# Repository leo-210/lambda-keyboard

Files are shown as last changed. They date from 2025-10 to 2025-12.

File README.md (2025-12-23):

# Lambda keyboard

A custom 36-key wired ChocV1 split keyboard.

> Note : this keyboard is my first design, and while taking it as an inspiration
> can be a good idea, please think before building exactly this design : there
> are a few flaws that I wrote about below.

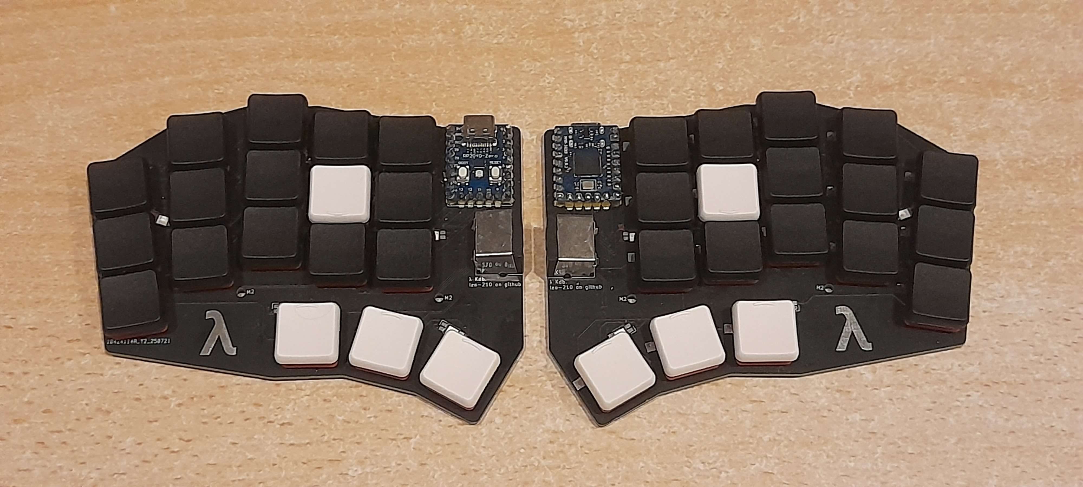
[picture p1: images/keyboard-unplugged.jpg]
Unplugged keyboard


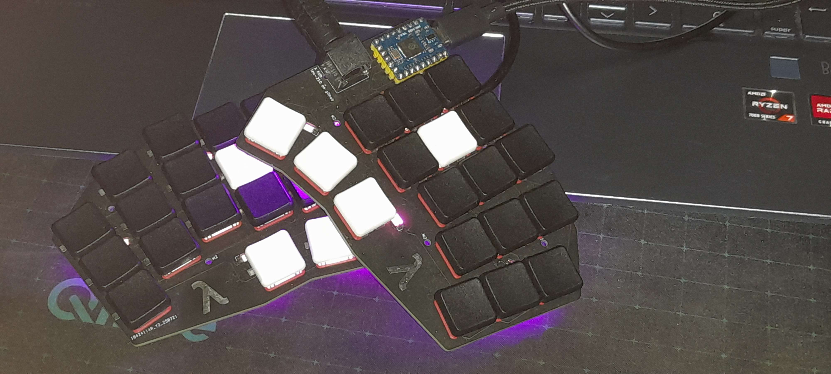
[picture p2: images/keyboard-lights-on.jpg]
Keyboard with lights on


# Building the keyboard

## Components

To build the keyboard, you'll need :
- 2 RP2040-Zero micro controllers
- 2 4-pin mini DIN connectors
- 5 YS-SK6812mini-e LEDs *(optional, the keyboard will work without them)*
- 36 Kailh hot-swappable sockets
- 36 **Choc v1** (and not Choc v2 !!) switches
- 36 **Choc v1** keycaps

The keyboard is diode-less !

You can also design your own case, but I did not bother.

## Price

Ordering everything in France, including soldering tools, it cost about 110 €,
where approximately a third was for electrical components and the PCB, a second
third for key caps and switches, and the last third for shipping costs.

## Firmware

This repo also contains QMK firmware for this keyboard, using the BÉPO french
layout. The keyboard layout was inspired by
[Miryoku](https://github.com/manna-harbour/miryoku), and you can view it on
[keyboard-layout-editor.com](https://www.keyboard-layout-editor.com/#/gists/44301debdf501308d3bc676f406fde57).

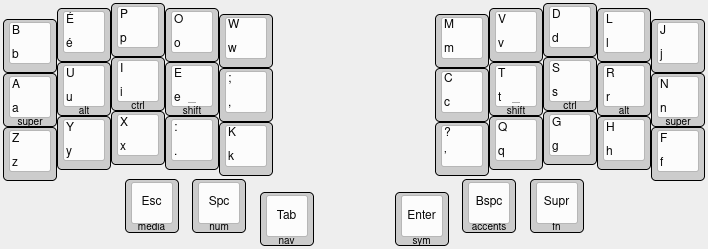
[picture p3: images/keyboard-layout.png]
Keyboard example layout


# About the project

## Why design yet another split keyboard ?

I fell into the rabbit hole of custom split keyboards, and with all the summer
holidays in front of me, I couldn't hold back. It was a fun project !

I chose to make my own design because none where satisfying all my requirements,
which were :
- Exactly 36 keys, I was afraid to go with only two thumb keys, but still wanted
  to go with few keys.
- A layout with enough stagger for my pinky.

With enough research I maybe could have found something, but designing it myself
was far more interesting. 

If you want a split keyboard, you can definitely think
about creating your own ! It is not as difficult as it would seem, and this
journey is well documented and there are a lot of tools to make your life
easier.

## Why lambda ?

I like this Greek letter, and my name starts with an L.

## Inspirations 

- the [Corne keyboard](https://github.com/foostan/crkbd) and the 
  [TOTEM keyboard](https://github.com/GEIGEIGEIST/TOTEM) for the layout (among 
  others)
- [axhixh/mini-kbd](https://github.com/axhixh/mini-kbd/tree/main) which helped
  me a lot to figure out the PCB design.

## What would I change ?

As my first design, nothing is perfect, and here are some things I would change
for a future design.

### A different connector

I like that the mini DIN protects my keyboard from shorting, but the cable is
really bulky. I'll think about changing to USB C next time, or just TRRS, even
with the lack of shorting safety.

### 4 rows instead of 3 to make writing french accents easier.

Writing in English is not a problem, but in french with accents everywhere I
find it painful to constantly use layers. It is possible and can even become
reliable, but for now I couldn't really get used to it (maybe I haven't used the
keyboard enough yet...).

Also, for coding, where a lot of special symbols are needed, a couple more keys
could be useful.

### More leds

Only 5 underglow LEDs are not enough in my opinion, you can see their light but
there are some "holes". Also, for a future keyboard I'd like per key lighting as
well, even if it requires more work.

### An OLED display

Seems fun.

### Writing JLCJLCJLC on the PCB

Without this text, JLC PCB wrote a random number in a random place on my PCBs...
Fortunately it does not look that bad.

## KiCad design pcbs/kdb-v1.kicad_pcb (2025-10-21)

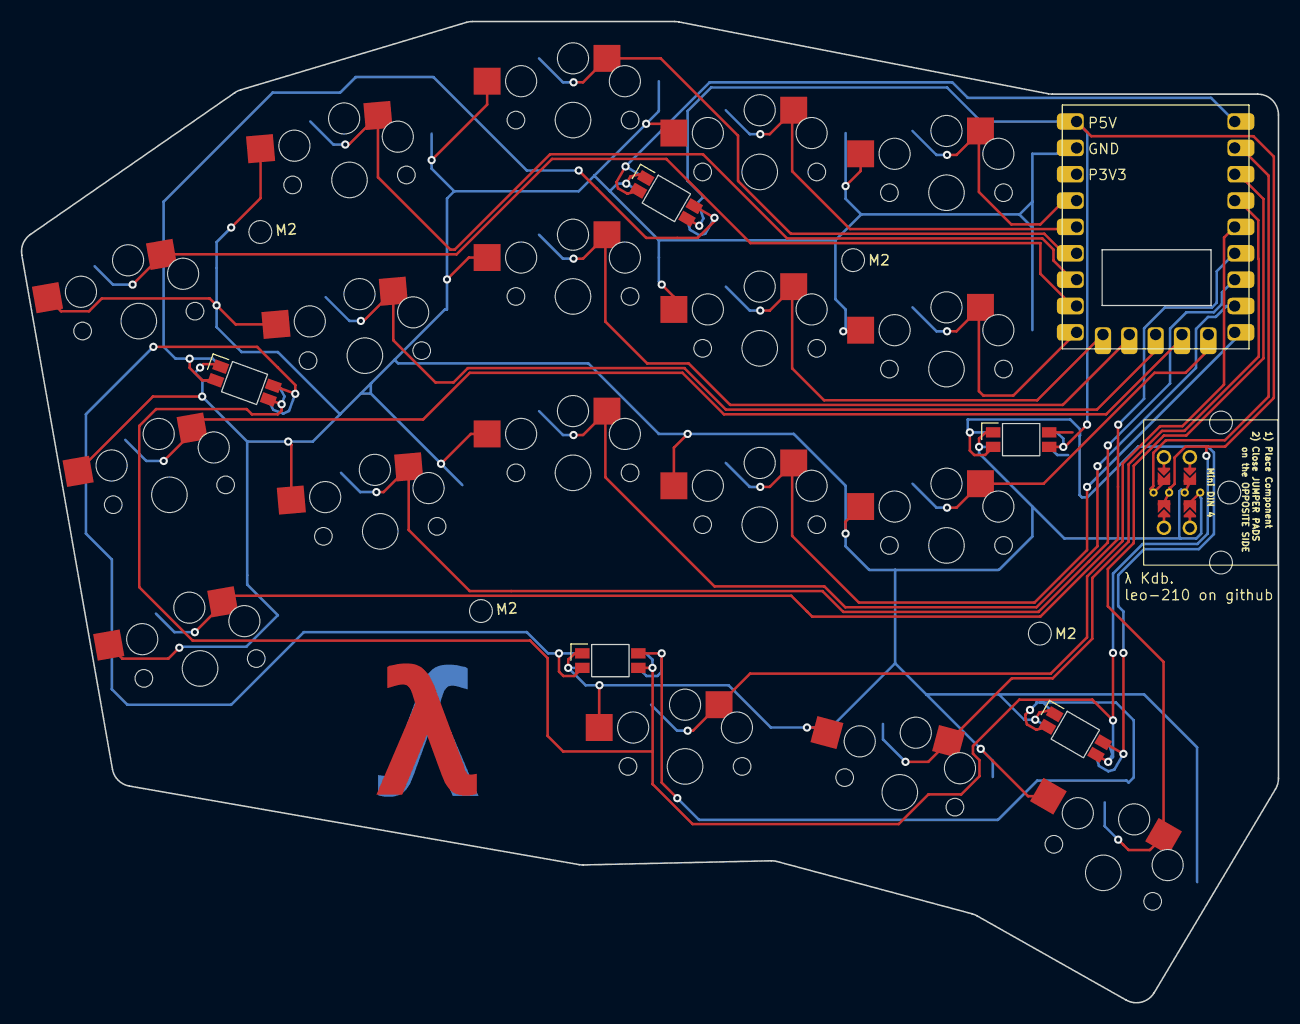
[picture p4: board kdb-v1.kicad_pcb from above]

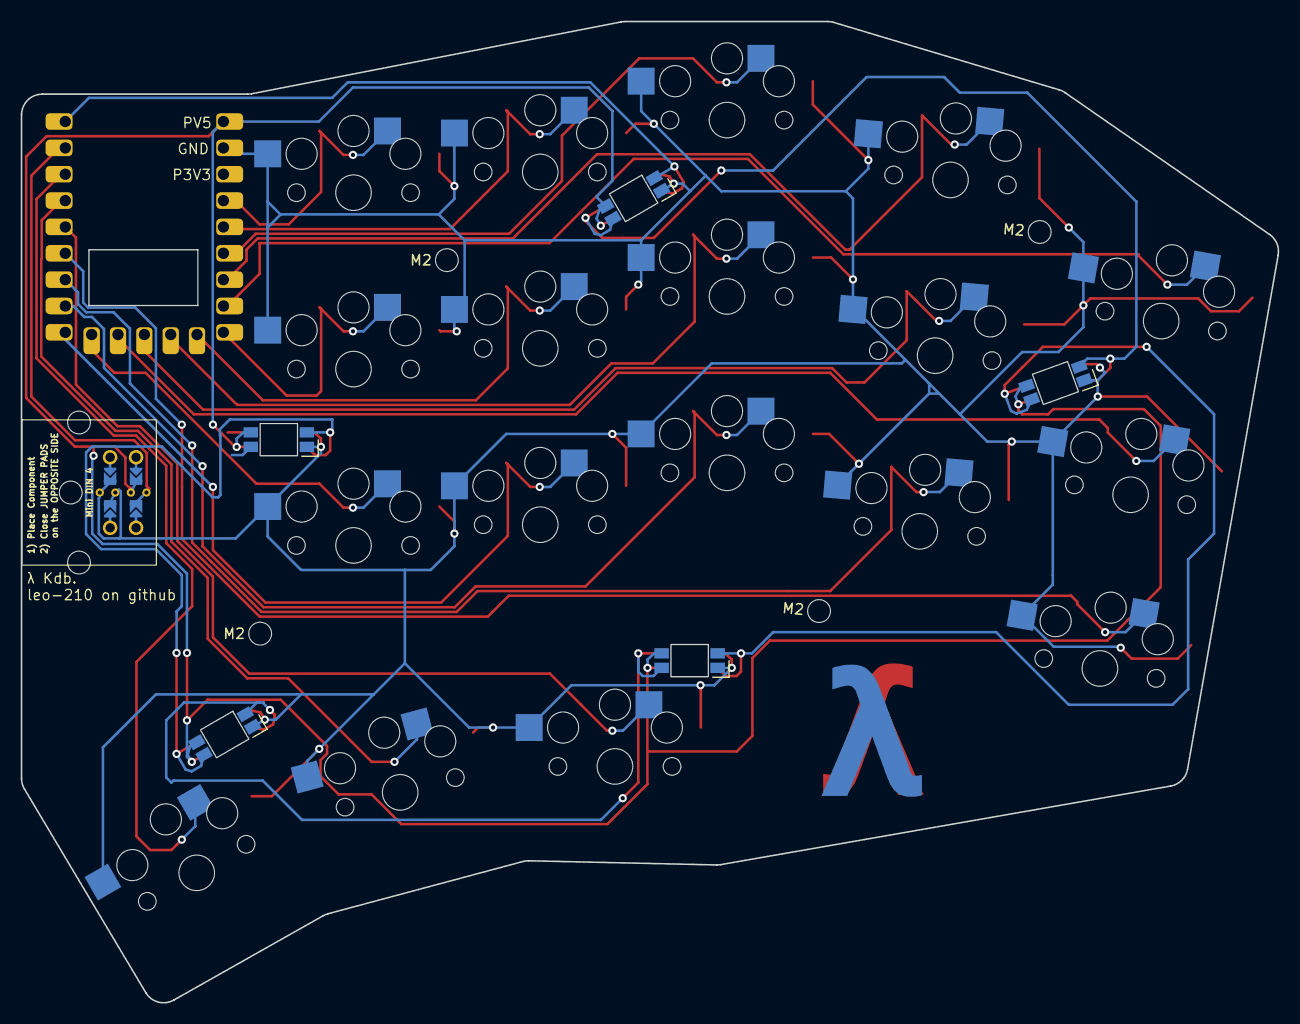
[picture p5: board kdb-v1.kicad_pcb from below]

Board: 2 copper layers, 121.2 x 94.6 mm, 29 parts (5 on the bottom side), 26 nets.

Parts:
AdamTech-MDJ004FS1: MiniDIN4; AdamTech_MDJ-004-FS_reversible
LED1, LED2, LED3, LED4, LED5: led_SK6812mini-e (underglow, reversible)
MH1, MH2, MH3, MH4: mounting_hole_npth
RP2040Zero1: RP2040-Zero
S1, S2, S3, S4, S5, S6, S7, S8, S9, S10, S11, S12, S13, S14, S15, S16, S17, S18: PG1350

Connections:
D1: LED1.4, LED2.2
D2: LED1.2, LED5.4
D3: LED4.4, LED5.2
D4: LED3.4, LED4.2
GND: AdamTech-MDJ004FS1.3, AdamTech-MDJ004FS1.5, LED1.3, LED2.3, LED3.3, LED4.3, LED5.3, RP2040Zero1.20, S1.2, S2.2, S3.2, S4.2, S5.2, S6.2, S7.2, S8.2, S9.2, S10.2, S11.2, S12.2, S13.2, S14.2, S15.2, S16.2, S17.2, S18.2
GP0: LED2.4, RP2040Zero1.1
GP1: AdamTech-MDJ004FS1.8, RP2040Zero1.2
GP2: RP2040Zero1.3, S18.1
GP3: RP2040Zero1.4, S17.1
GP4: RP2040Zero1.5, S16.1
GP5: RP2040Zero1.6, S1.1
GP6: RP2040Zero1.7, S4.1
GP7: RP2040Zero1.8, S7.1
GP8: RP2040Zero1.9, S10.1
GP9: RP2040Zero1.10, S13.1
GP10: RP2040Zero1.11, S2.1
GP11: RP2040Zero1.12, S5.1
GP12: RP2040Zero1.13, S8.1
GP13: RP2040Zero1.14, S11.1
GP14: RP2040Zero1.15, S14.1
GP15: RP2040Zero1.16, S3.1
GP26: RP2040Zero1.17, S6.1
GP27: RP2040Zero1.18, S9.1
GP28: RP2040Zero1.22, S12.1
GP29: RP2040Zero1.23, S15.1
P5V: AdamTech-MDJ004FS1.6, LED1.1, LED2.1, LED3.1, LED4.1, LED5.1, RP2040Zero1.19

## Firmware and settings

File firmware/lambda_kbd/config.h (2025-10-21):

#pragma once

#define RP2040_BOOTLOADER_DOUBLE_TAP_RESET
#define RP2040_BOOTLOADER_DOUBLE_TAP_RESET_TIMEOUT 1000U

#define SERIAL_USART_TX_PIN GP1

#define EE_HANDS

#define TAPPING_TERM 250
#define FLOW_TAP_TERM 50

#define WS2812_DI_PIN GP0
#define RGBLIGHT_LED_COUNT 5
#define RGBLIGHT_SPLIT
